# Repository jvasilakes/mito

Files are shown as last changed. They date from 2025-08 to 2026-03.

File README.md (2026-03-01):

# Mito

A tiny, cheap, hackable, completely open-source force gauge for isometric finger strength training.

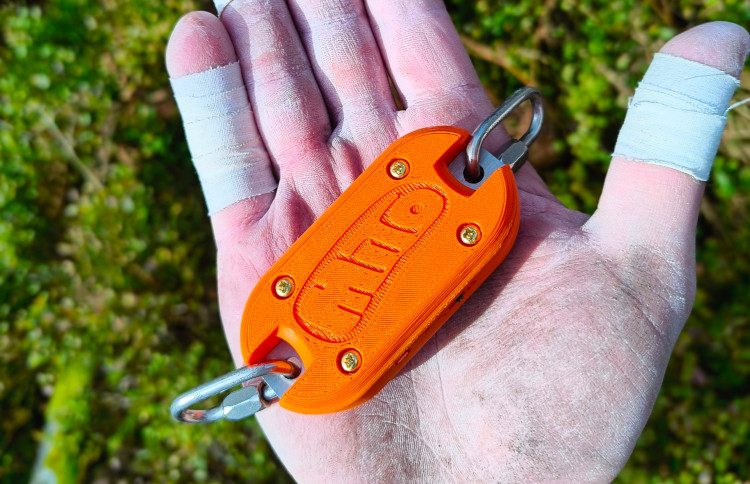
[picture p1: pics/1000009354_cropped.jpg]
Mito


## Hardware information

The Mito is based on the Seeed XIAO NRF52840 microcontroller, an HX711 ADC, and a custom load cell. It runs at approximately 80 samples per second on the hardware side, and sends approximately 60 samples per second over bluetooth. Initial tests show a standard error of about 100g. The load cell and two Peguet 3.5mm stainless steel maillon rapides provide a working load limit of 220kg and a breaking load of 1100kg. 

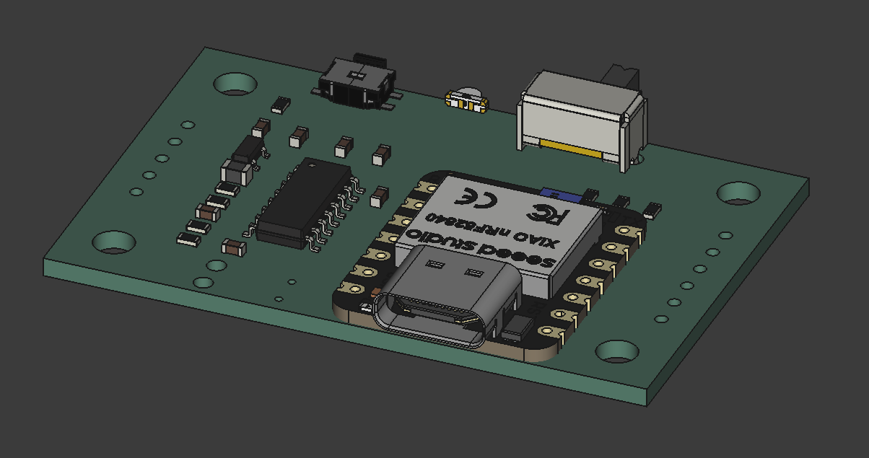
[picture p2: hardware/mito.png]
Mito PCB


## User Guide

On one side of your device you'll see

 1. A hardware on/off switch
 2. An LED indicator
 3. A tare button

On the other there is a USB-C port that is used for battery charging and firmware updates.

Assuming you've obtained a prebuilt device, it should be ready to go out of the box. Flip the switch to turn it on, and you'll see a green light for 1 second before it changes to yellow. Download the Frez app on your phone, register/sign in to your account, then press the "connect" button on the main page. If the Mito is powered on, a scan of available devices should reveal a device called "Progressor". Connect to it, register it as "Mito" or whatever name you like, and start training!

### Automatic sleep mode

After 1 minute of inactivity (i.e., no weight changes) the Mito will enter sleep mode to save battery. This is indicated by a periodic flashing LED. To wake your Mito up, simply press the tare button and continue your training. After 10 minutes in light sleep, the Mito will enter deep sleep from which it can only be woken up by turning it off and on again.

### Charging the battery

The Mito should need charging very infrequently. The current estimate is at least a few weeks of regular usage before the battery will run low. To charge, plug the Mito into a power source using a USB-C cable and turn it on with the hardware switch. The Mito will enter sleep mode after 1 minute of inactivity and continue to charge, indicated by a longer blinking LED.

### Firmware updates

Firmware updates will be provided here on the Releases page, so keep an eye out. To update your device's firmware with a new version, follow these steps:

 1. Download the new firmware UF2 file onto your computer (e.g., `mito_v0.0.1.uf2`).
 2. Plug your Mito into your computer using the USB-C port while holding down the tare button. Release the button once you see the red light. You've now entered maintenance mode selection.
 3. Use single presses of the tare button to cycle through the maintenance modes until you see a blue light, which indicates firmware update mode. Double click the tare button to select it.
 4. The Mito should turn off and after a few moments a USB device called XIAO-SENSE should pop up on your computer. Simply drag and drop the new UF2 file onto the root folder of this device. Once the copy is complete, the Mito should reset.
 5. Unplug the USB cable and start training!

### Changing the default device mode

The Mito is compatible with the Frez app for visualizing and tracking your training sessions. By default the Mito is in Tindeq mode (yellow light), meaning that it pretends to be a Tindeq device. This mode currently provides the most stable and fastest bluetooth connection to the Frez app. The Tindeq app is currently not supported, and your experience may vary.

If for whatever reason you want your Mito to pretend to be a WH-06 (the original device around which Frez was built), follow these steps:

 1. Turn your Mito on with the hardware switch.
 2. While the initial green light is showing, press the tare button to enter device selection mode. The light should turn blue.
 3. A single press of the tare button will cycle through the available device modes. Blue indicates the WH-06 while yellow indicates the Tindeq.
 4. Press the tare button twice quickly to change the default device to the current selection. The Mito will start up and from now on will be in your chosen device mode every time you turn it on.

If you want to abort this and stay with your current default device, simply turn the Mito off and back on again.

## Known Issues

### Frez Connectivity

It can happen that if you connect your Mito to Frez or another app (e.g., Tindeq), close the app, and the try to reconnect, the initialization will hang and you'll get a device disconnected error. This can be fixed by simply turning the Mito off and on again, and restarting the app.

### Battery Level Indicator

Frez shows battery level next to the connected device icon in the lower right corner. Unfortunately, the battery level sampling on the XIAO microcontroller isn't the most accurate, so you may see inconsistnet values. Overall, however, a low battery indication here is a good sign its time to charge.

## Advanced Usage

### Calibration

All pre-built Mito's are already calibrated. If you need to redo it however, follow these steps:

 1. Download [Serial Bluetooth Terminal](https://play.google.com/store/apps/details?id=de.kai_morich.serial_bluetooth_terminal&pcampaignid=web_share) app on your phone. 
 2. Turn on the Mito while holding down the tare button to enter maintenance mode.
 3. Use single presses of the tare button to cycle through modes until you see a white light. Press the tare button twice quickly to select this, which will enter calibration mode.
 4. Open the Serial Bluetooth Terminal app, scan for devices, and select the Mito.
 5. A terminal window should open. Hang the Mito on something solid, but keep the other anchor free. Once you see `Connecting to Mito... Connected` in the terminal window, send an empty command to start the calibration process. 
 6. After you see `Tared. Enter weight. grams: ` in the terminal, hang a known weight on the free anchor of the Mito. Make sure the weight is stationary and not swinging, twirling, etc.
 7. Enter the weight in grams (e.g., for a 20kg plate you would enter `20000`) and hit send.
 8. The calibration will now run for a few iterations. At the end it will print `Estimated parameter:  Saving...`. 
 9. Power cycle the Mito, connect to the Frez app, and validate that the reading is correct for the weight you used to calibrate. 

### Configuration

You can manually set the following variables in `prototype/src/lib/config.h`. For the changes to take effect, you will need to recompile and upload the firmware to your Mito (see below).

 * `LIGHT_SLEEP_SECONDS`: The number of seconds with no weight changes until the Mito enters light sleep. Default 60.
 * `DEEP_SLEEP_SECONDS`: The number of seconds in light sleep until the Mito enters deep sleep. Default 600.
 * `SCALE_FACTOR`: The calibration scale factor. Default set during calibration (see above). This can be used to fine-tune your precise calibration factor.

### Building the firmware

First, clone this repository or download the code for your chosen release. Then,

```
cd dev
arduino-cli compile --export-binaries --fqbn Seeeduino:nrf52:xiaonRF52840Sense prototype
python ../utils/uf2conv.py prototype/build/Seeeduino.nrf52.xiaonRF52840Sense/prototype.ino.hex --family 0xADA52840 --convert --output prototype/releases/mito_vX.X.X.uf2 
```

Change the `X.X.X` to your desired version. If you've made changes to an official release, I recommend adding a suffix to indicate it (e.g., `mito_v0.0.4_dev.uf2`).

### Debug Mode

If you're doing development and want to access information over serial, plug your Mito into your computer while holding down the tare button. Use single presses of the tare button until you see a red light. Double click the tare button to enter debug mode. In this mode, the Mito will not start its initialization routine until you've connected to it with a serial monitor. 

Once the Mito has begun measuring, it will print data in the following format for each measurement taken from the ADC:

`adc_reading,smoothed_adc_reading,scale_offset,scale_calibration_factor,weight_grams,device_sample_rate_hz,ble_notify_rate_hz,battery_is_charging,battery_voltage,battery_percentage`

It will also print out any commands it receives from the central, and when the device is charging in sleep mode it will print out the current battery percentage.

### Entering firmware update mode with the hardware reset button

It might happen that a failed firmware update means that you can't enter firmware update mode using the method described above. If this happens you'll have to use the hardware reset button on the microcontroller. You can do this in two ways:

 1. Insert a small thin object into the hole below the 'S' on the CRUX TOOLS side of the Mito. a bobby pin works great for this. You'll have to fish around a bit, but the XIAO's reset button should be directly below this. Do your best to double click it. If you're successful, the Mito will turn off and you'll see the XIAO-SENSE USB device pop up on your computer. 
 2. If the above is simply too annoying, you can also open the case using a standard Philip's head screwdriver. If you do this, there is a chance you will have to re-calibrate after putting it together again, since the load cell can get shifted slightly.

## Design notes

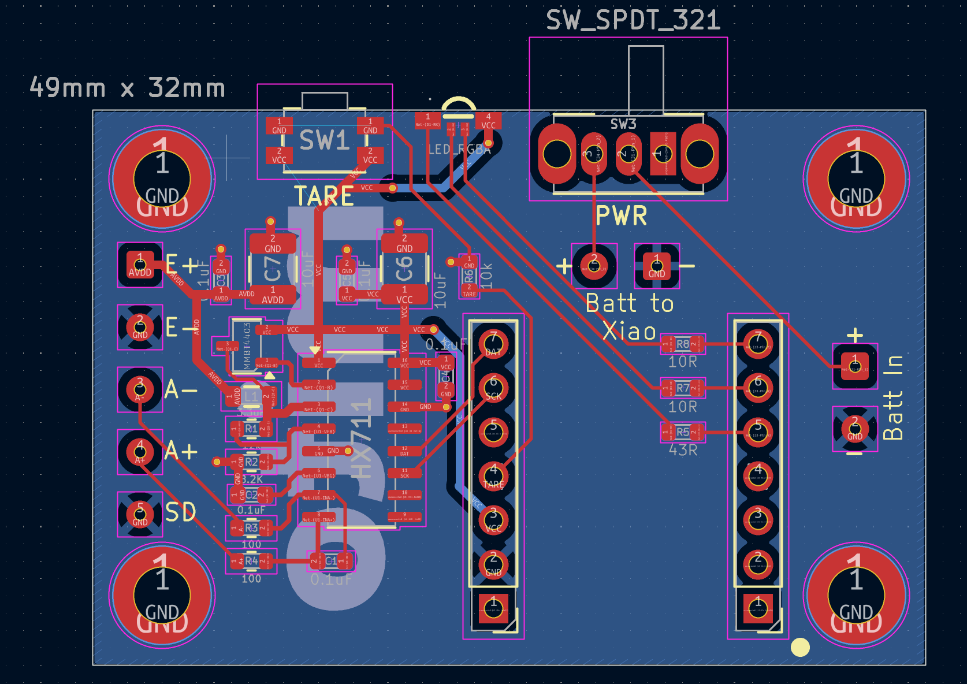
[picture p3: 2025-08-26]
hardware/img/pcb.png

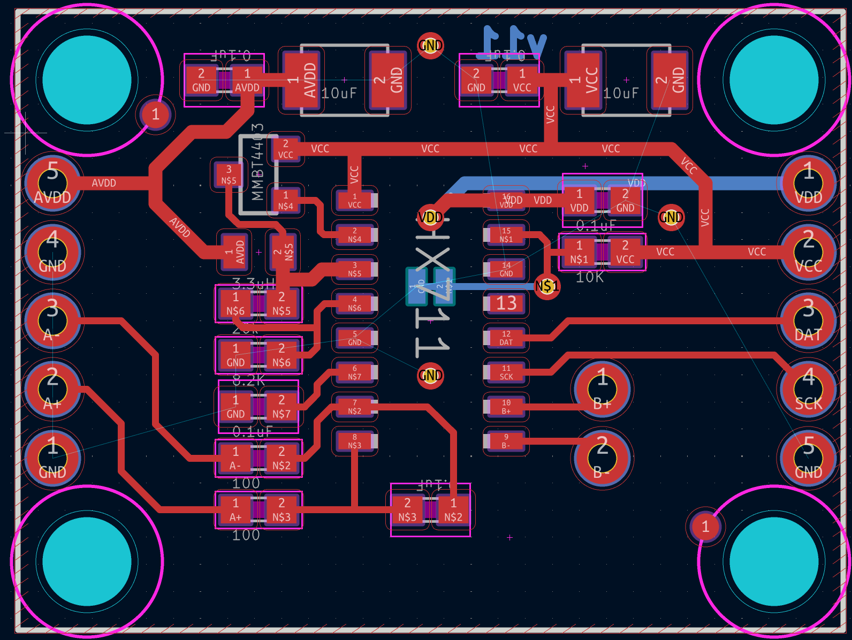
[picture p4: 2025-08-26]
hardware/sparkfun_layout.png

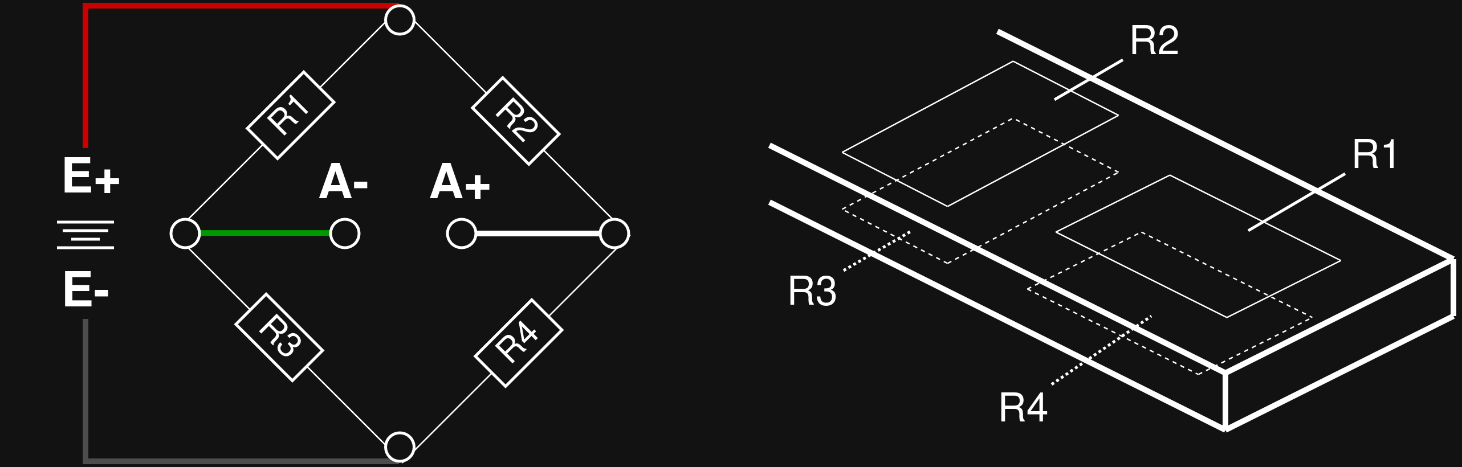
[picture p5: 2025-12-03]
pics/load_cell_diagram.png

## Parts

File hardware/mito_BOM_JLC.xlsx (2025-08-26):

reference | quantity | value | footprint | part_number
R1 | 1 | 12k | R_0603 | C22790
R2 | 1 | 8.2K | R_0603 | C309082
R3,R4,R8,R7 | 4 | 100R | R_0603 | C25201
R5 | 1 | 180R | R_0603 | C25210
R6 | 1 | 10k | R_0603 | C95204
C1,C2,C3,C4,C5 | 5 | 0.1uF | C_0603 | C24452
C6,C7 | 2 | 10uF | C_1210 | C39232
L1 | 1 | 3.3uH | L_0805 | C51725
Q1 | 1 | MMBT4403 | SOT-23-3 | C8513
U1 | 1 | HX711 | SOIC-16_3.9x9.9mm_P1.27mm | C6705483
D1 | 1 | LED_RGBA | LED-SMD_LTST-S310F3WT | C284951
SW1 | 1 | SW_Push | Panasonic_EVQPUJ_EVQPUA | C128539
PWR | 1 | SW_SPDT_321 | SW_Slide_SPDT_Angled_CK_OS102011MA1Q | C226259

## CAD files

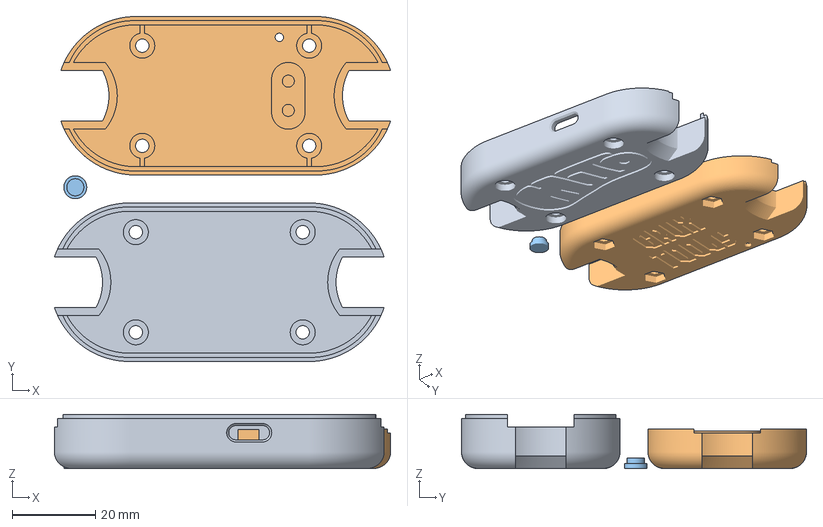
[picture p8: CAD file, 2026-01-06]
hardware/enclosure/enclosure_v3.3mf
80.6 x 82.7 x 13.0 mm
enclosure3-Bottom
enclosure3-Top
button3

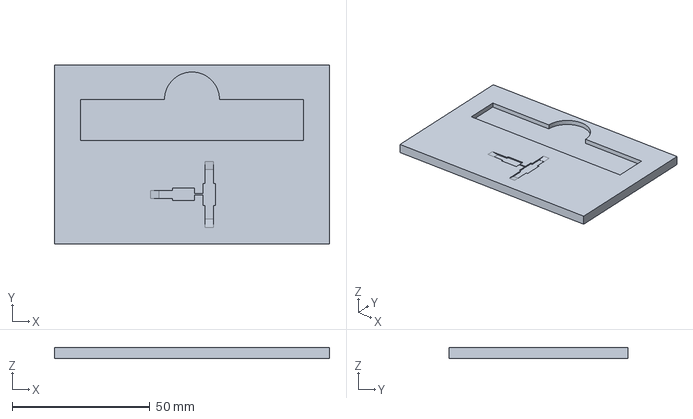
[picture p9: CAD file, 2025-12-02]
hardware/load_cell/build_plate.FCStd
100.0 x 65.0 x 4.00 mm

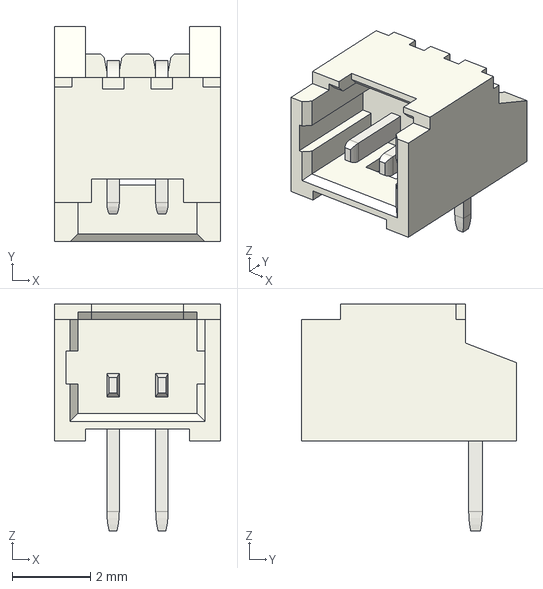
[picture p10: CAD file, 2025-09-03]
hardware/Molex_PicoBlade_53048-0210.stp
4.25 x 5.50 x 5.80 mm

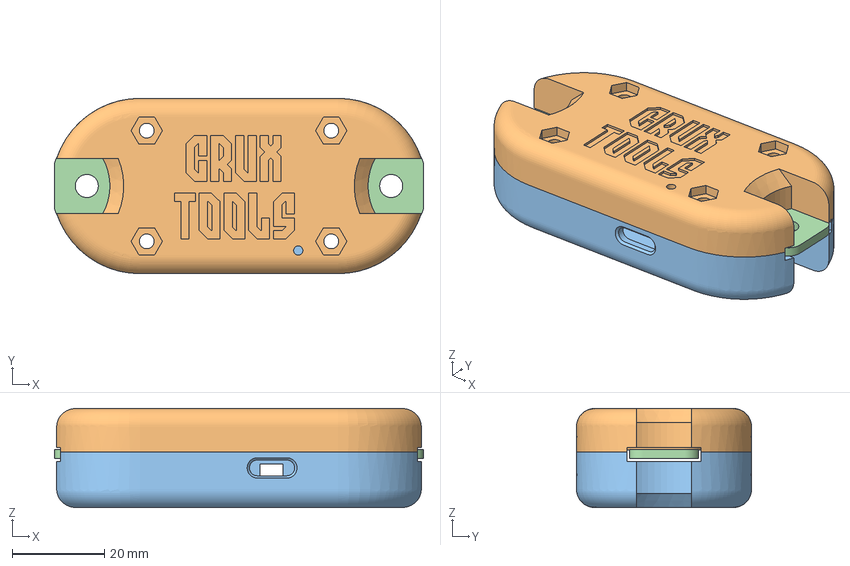
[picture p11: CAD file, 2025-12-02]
hardware/enclosure/enclosure2.FCStd
80.0 x 38.0 x 21.5 mm
button_cutout003
top
bottom
load_cell

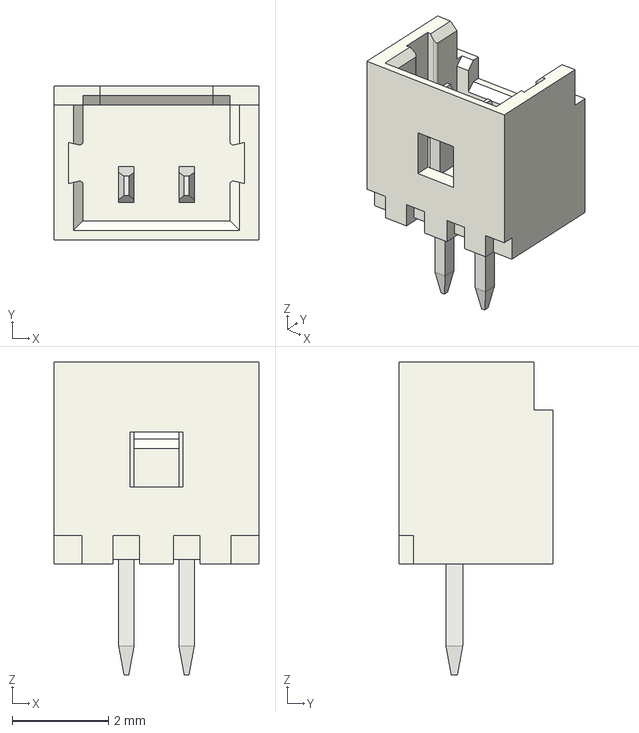
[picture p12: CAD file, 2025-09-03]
hardware/Molex_PicoBlade_53047-0210.stp
4.25 x 3.20 x 6.50 mm

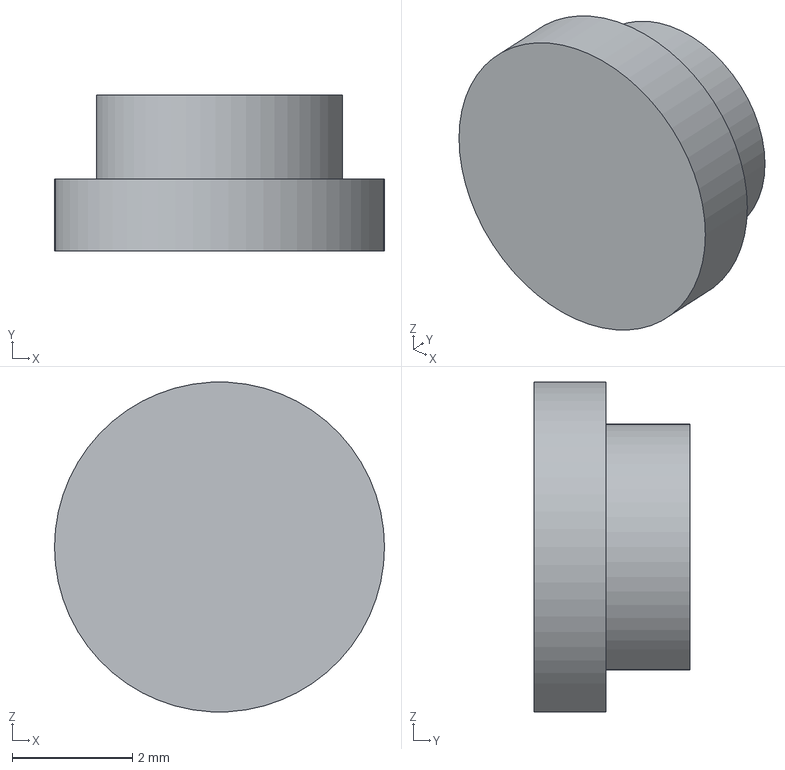
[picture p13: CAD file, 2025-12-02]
hardware/enclosure/button3.step
5.50 x 2.60 x 5.49 mm

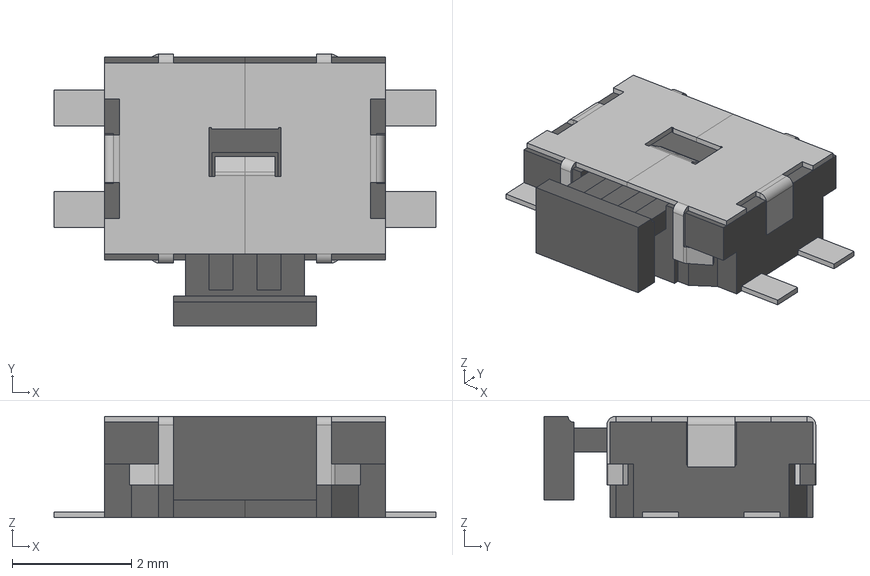
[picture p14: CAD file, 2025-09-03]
hardware/Panasonic_EVQPUJ_EVQPUA.step
6.40 x 4.55 x 1.70 mm

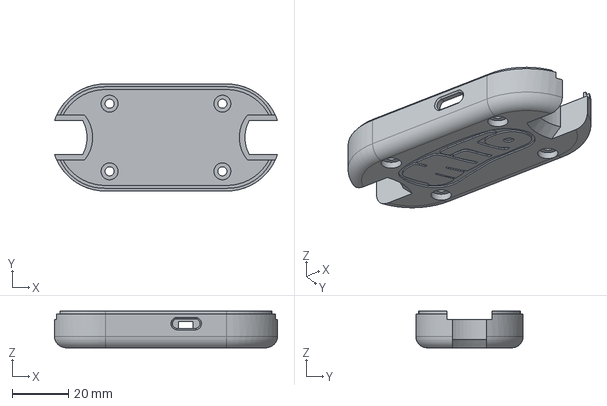
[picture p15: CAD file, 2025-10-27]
hardware/enclosure/enclosure3-Bottom.step
79.1 x 38.0 x 13.0 mm

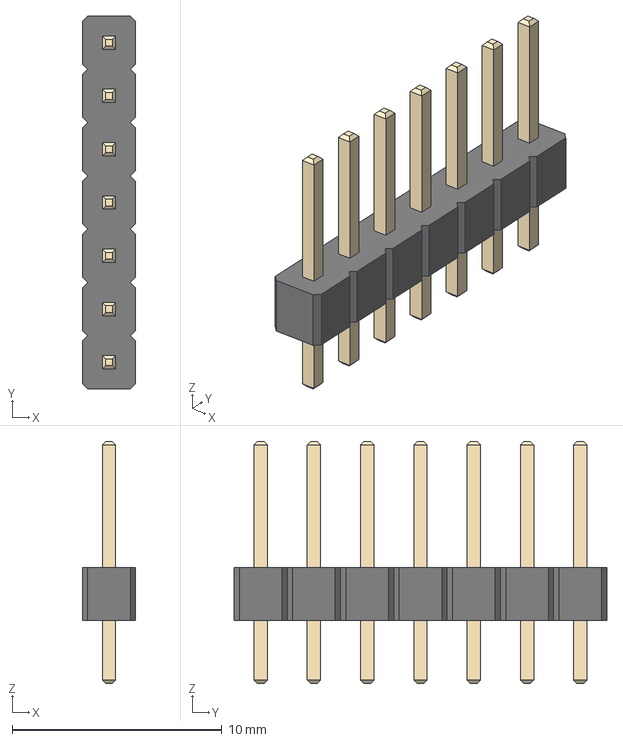
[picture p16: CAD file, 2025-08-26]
hardware/PinHeader_1x07_P2.54mm_Vertical.step
2.54 x 17.8 x 11.5 mm

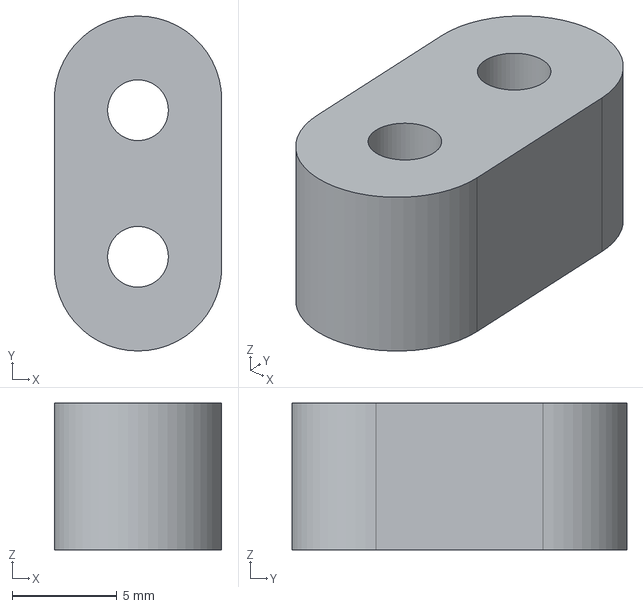
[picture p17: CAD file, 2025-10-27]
hardware/enclosure/load_cell_standoff.step
8.00 x 16.0 x 7.00 mm

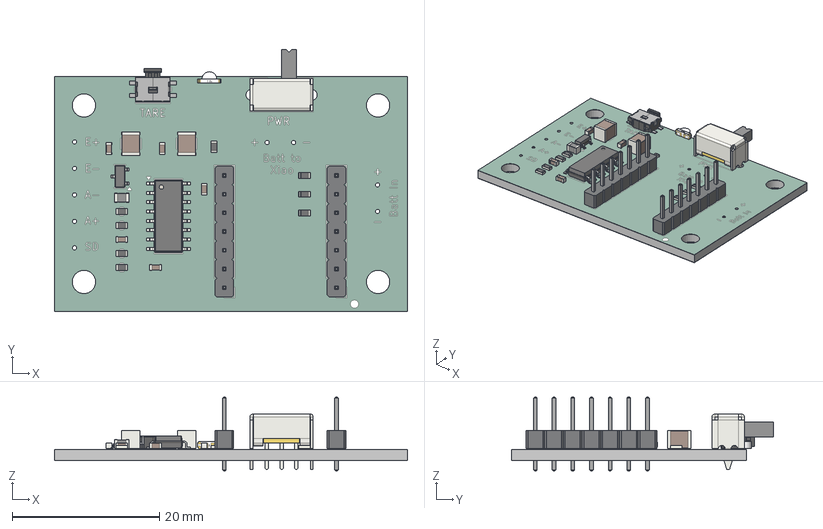
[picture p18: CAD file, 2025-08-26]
hardware/mito.step
48.0 x 35.7 x 10.0 mm
R_0603 x 4
R_0603_1608Metric x 4
SW_Slide_SPDT_Angled_CK_OS102011MA1Q
pinheader_short-pinheader x 2
C_0603 x 5
LED-ARRAY-SMD_4P-L3.2-W1.5-H1.0
C_1210_3225Metric x 2
SOIC-16_3.9x9.9mm_P1.27mm
L_0805
Pocket008_(Mirror_#2)
Pad007_(Mirror_#3)
Pad007_(Mirror_#5)
Pad007_(Mirror_#4)
SOT-23-3
mito_silkscreen
mito_soldermask
mito_PCB

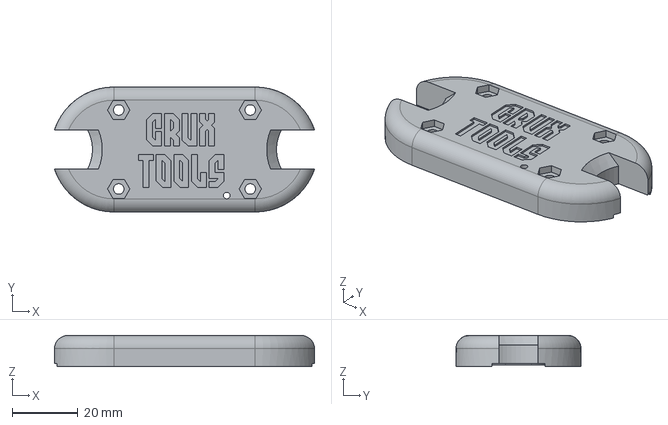
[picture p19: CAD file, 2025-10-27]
hardware/enclosure/enclosure3-Top.step
79.1 x 38.0 x 9.50 mm

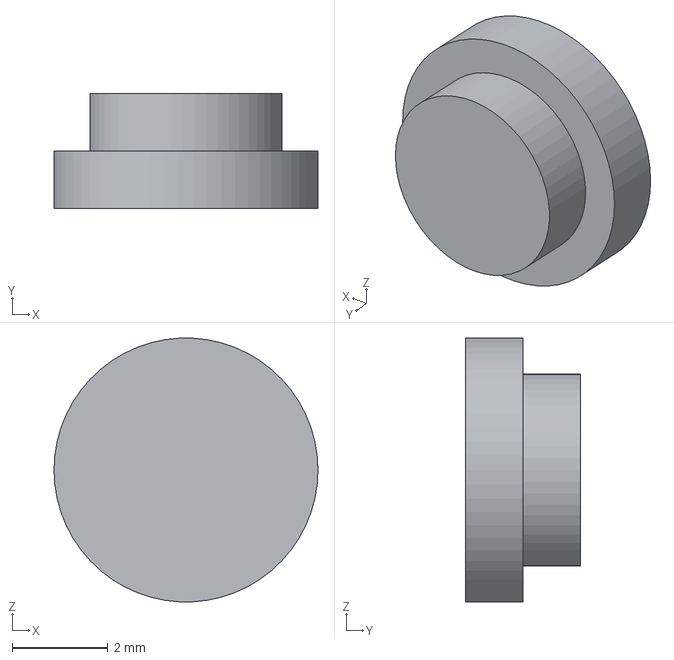
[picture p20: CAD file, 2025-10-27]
hardware/enclosure/button2.step
5.50 x 2.40 x 5.49 mm

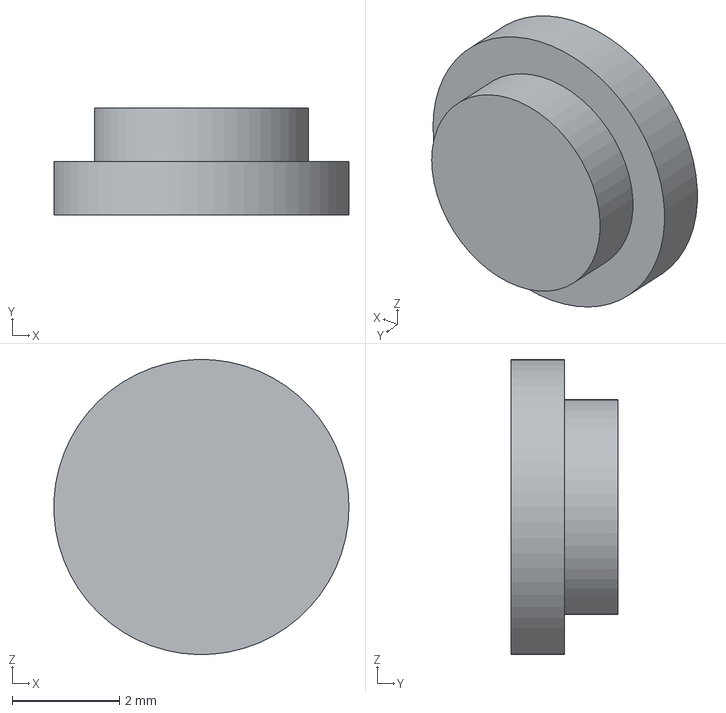
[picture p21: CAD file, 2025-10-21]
hardware/enclosure/button.step
5.50 x 2.00 x 5.50 mm

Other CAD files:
hardware/enclosure/enclosure2-Bottom.step
hardware/enclosure/enclosure2-Top.step
hardware/enclosure/enclosure_bottom_with_window.3mf
hardware/enclosure/enclosure_bottom.3mf
hardware/enclosure/enclosure.FCStd
hardware/enclosure/enclosure2-Bottom_window.step
hardware/enclosure/enclosure2-Bottom_with_window.step
hardware/enclosure/load_cell.stl
hardware/enclosure/transparent_test.3mf
hardware/load_cell/build_plate.3mf
hardware/load_cell/build_plate.stl

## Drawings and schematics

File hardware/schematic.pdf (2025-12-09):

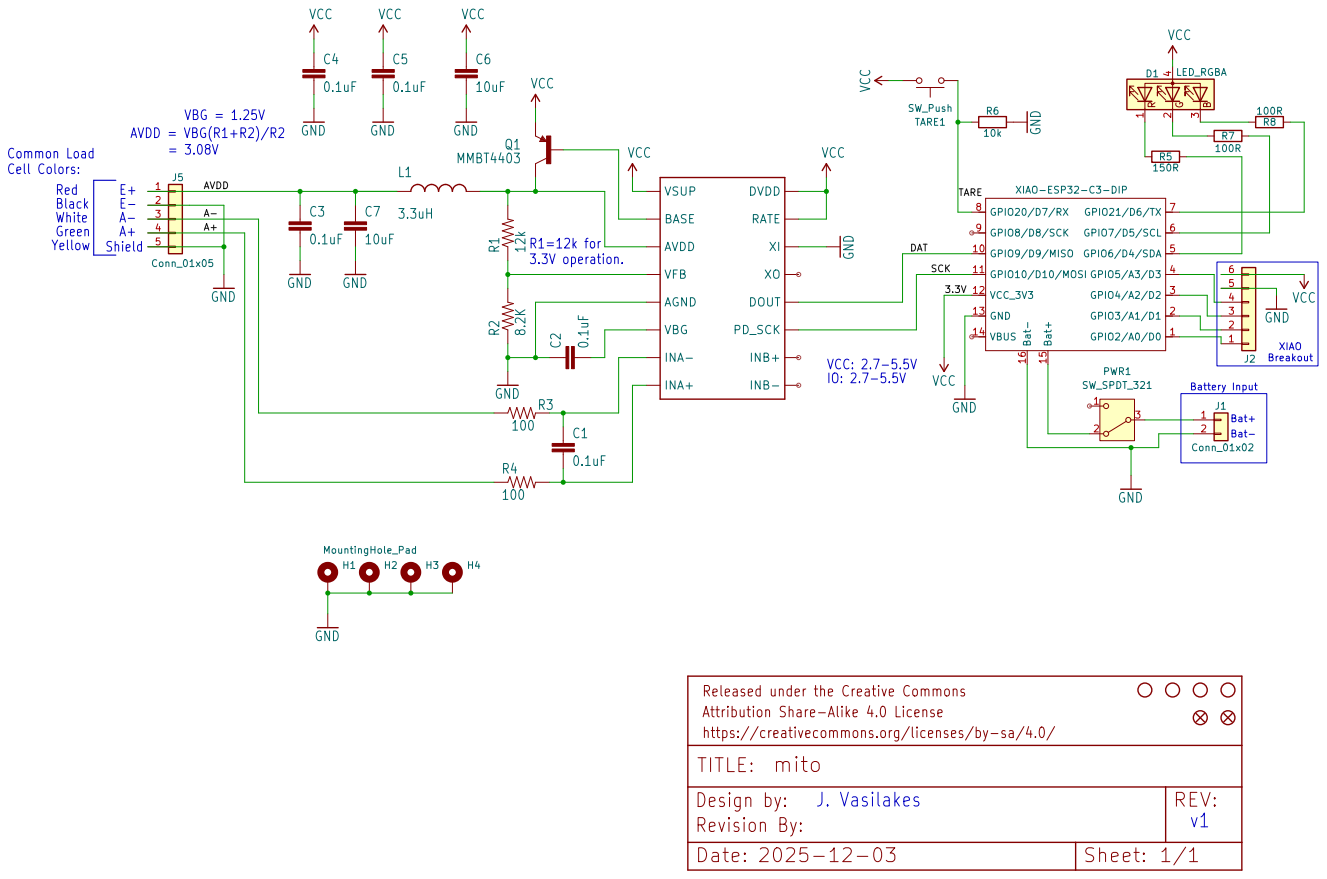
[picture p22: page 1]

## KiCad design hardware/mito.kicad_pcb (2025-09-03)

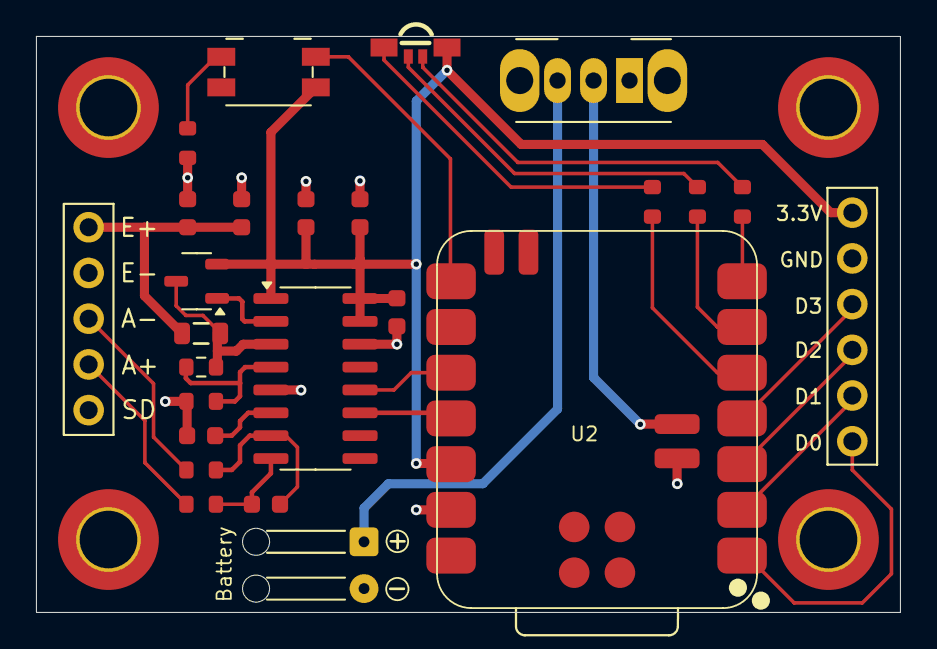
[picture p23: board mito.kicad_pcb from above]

Board: 2 copper layers, 48.0 x 32.0 mm, 30 parts (0 on the bottom side), 26 nets.

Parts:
C1, C2, C3, C4, C5: 0.1uF; C_0603
C6, C7: 10uF; C_0603
D1: LED_RGBA; LED-SMD_LTST-S310F3WT
FRAME1: FRAME-LETTER; CREATIVE_COMMONS
H1, H2, H3, H4: MountingHole_Pad; MountingHole_3.2mm_M3_DIN965_Pad_TopOnly
J1: Conn_01x02; SolderWire-0.1sqmm_1x02_P3.6mm_D0.4mm_OD1mm_Relief
J2: Conn_01x06; PinHeader_1x06_P2.54mm_Vertical
J5: Conn_01x05; PinHeader_1x05_P2.54mm_Vertical
L1: 3.3uH; L_0805
PWR1: SW_SPDT_321; SW_Slide_SPDT_Angled_CK_OS102011MA1Q
Q1: MMBT4403; SOT-23-3
R1: 12k; R_0603_1608Metric
R2: 8.2K; R_0603
R3, R4: 100; R_0603
R5: 150R; R_0603
R6: 10k; R_0603
R7, R8: 100R; R_0603
TARE1: SW_Push; Panasonic_EVQPUJ_EVQPUA
U1: HX711; SOIC-16_3.9x9.9mm_P1.27mm
U2: XIAO-ESP32-C3-DIP; XIAO-nRF52840-SMD

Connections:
/A+: J5.4, R4.1
/A-: J5.3, R3.1
/AVDD: C3.1, C7.1, J5.1, L1.1
/DAT: U1.12 (DOUT), U2.10 (GPIO9/D9/MISO)
/SCK: U1.11 (PD_SCK), U2.11 (GPIO10/D10/MOSI)
/TARE: R6.1, TARE1.1, U2.8 (GPIO20/D7/RX)
GND: C2.1, C3.2, C4.2, C5.2, C6.2, C7.2, H1.1, H2.1, H3.1, H4.1, J1.2, J2.5, J5.2, J5.5, R2.1, R6.2, U1.5 (AGND), U1.14 (XI), U2.13 (GND), U2.16 (Bat-)
unnamed: D1.3 (BK), R8.1
unnamed: D1.2 (GK), R7.1
unnamed: D1.1 (RK), R5.1
unnamed: J1.1, PWR1.3 (B)
unnamed: J2.1, U2.1 (GPIO2/A0/D0)
unnamed: J2.2, U2.2 (GPIO3/A1/D1)
unnamed: J2.3, U2.3 (GPIO4/A2/D2)
unnamed: J2.4, U2.4 (GPIO5/A3/D3)
unnamed: PWR1.2 (A), U2.15 (Bat+)
unnamed: Q1.1 (B), U1.2 (BASE)
unnamed: L1.2, Q1.3 (C), R1.2, U1.3 (AVDD)
unnamed: C1.2, R4.2, U1.8 (INA+)
unnamed: C1.1, R3.2, U1.7 (INA-)
unnamed: C2.2, U1.6 (VBG)
unnamed: R1.1, R2.2, U1.4 (VFB)
unnamed: R5.2, U2.5 (GPIO6/D4/SDA)
unnamed: R7.2, U2.6 (GPIO7/D5/SCL)
unnamed: R8.2, U2.7 (GPIO21/D6/TX)
VCC: C4.1, C5.1, C6.1, D1.4 (A), J2.6, Q1.2 (E), TARE1.2, U1.1 (VSUP), U1.15 (RATE), U1.16 (DVDD), U2.12 (VCC_3V3)

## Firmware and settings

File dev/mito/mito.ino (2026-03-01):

#include <iostream>
#include <memory>
#include <string.h>
#include <Adafruit_TinyUSB.h>
#include "lib/config.h"
#include "lib/battery.h"
#include "lib/HX711.h"
#include "lib/flash.h"
#include "lib/scales.h"


/* Set in setup() */
uint8_t DEVICE_CODE;  // 0: WH06  1: Tindeq
int NUM_DEVICES = 2;

// Tare button
const uint8_t tarePin = 7;  // the tare button
bool tareState = 0;  // tare button push state.

bool debug = 0;  // Enter debug mode, which opens serial over usb.
bool doCalibrate = 0;  // Enter calibration mode.
bool enter_dfu = 0;  // Enter DFU mode and reset.

// RGB LED pins
const uint8_t redPin = 4;    // the number of the LED pin
const uint8_t greenPin = 5;    // the number of the LED pin
const uint8_t bluePin = 6;    // the number of the LED pin
// Current LED color
uint8_t color[3] = { 0, 0, 0 };

// Load Cell parameters
const uint8_t LOADCELL_DOUT_PIN = 9;
const uint8_t LOADCELL_SCK_PIN = 10;
const uint8_t LOADCELL_GAIN = 128;

// Parameter for Exponential Moving Average
int WEIGHT_EMA_ALPHA = 75;
int BATT_EMA_ALPHA = 10;

/* ========== Global Variables ========== */
bool first_loop = 1;
long reading = 0;  // Raw ADC reading.
long smoothed_reading = 0;  // For computing exponential moving average.
uint32_t weight = 0;  // Current weight reading in grams.
uint32_t prev_weight = 0;  // Previous weight reading in grams.

uint32_t curr_time = 0;  // Current time stamp
uint32_t prev_time = 0;  // To measure increments without delay() 

uint32_t measure_time = 0;  // Microseconds since measurement started
uint32_t start_measure_time = 0;  // Microseconds since measurement started
uint32_t hz_time = 0;    // For measuring device and BLE Hz
bool currently_measuring = 0;

// Convert to milliseconds
uint32_t light_sleep_timeout = LIGHT_SLEEP_SECONDS * 1000;
uint32_t deep_sleep_timeout = DEEP_SLEEP_SECONDS * 1000;
uint32_t sleepTimeoutStart = 0;

uint16_t num_samples = 0;  // Number of samples obtained from the ADC
uint16_t num_packets = 0;  // Number of samples obtained from the ADC
uint16_t device_hz = 0;    // For measuring HX711 speed
uint16_t ble_hz = 0;       // For measuring BLE speed

float avg_battery_voltage = 0.0;
float prev_vbat = -1.0;

/* ========= The device =========== */
HX711 scale;  // The HX711 ADC
Device* device = nullptr;  // The overall device: WH06, Tindeq
XiaoBattery battery;  // The battery ADC

void setLEDColor(uint8_t red, uint8_t green, uint8_t blue)
{
  // Set the LED color based on RGB values.
  // Assumes common anode RGB LED
  digitalWrite(redPin, 255 - red);
  digitalWrite(greenPin, 255 - green);
  digitalWrite(bluePin, 255 - blue);
}

uint8_t* getLEDColor(void)
{
  uint8_t* rgb = new uint8_t[3];
  rgb[0] = 255 - digitalRead(redPin); 
  rgb[1] = 255 - digitalRead(greenPin); 
  rgb[2] = 255 - digitalRead(bluePin); 
  return rgb;
}

void turnOffLED(void)
{
  // Turn off the LED.
  digitalWrite(redPin, HIGH);
  digitalWrite(greenPin, HIGH);
  digitalWrite(bluePin, HIGH);
}

void flashLED(void)
{
  // Flash the LED on and off with the current color.
  // Used to indicate tare.
  uint8_t* rgb = getLEDColor();
  for (int i=0; i<3; i++) {
    turnOffLED();
    delay(100);
    setLEDColor(rgb[0], rgb[1], rgb[2]);
    delay(100);
  }
  delete[] rgb;
}

template <typename T>
void debugPrint(T msg)
{
  if (debug == 1) {
    Serial.print(msg);
  }
}

template <typename T>
void debugPrintln(T msg)
{
  if (debug == 1) {
    Serial.println(msg);
  }
}

void tare(void)
{
  debugPrintln("Taring...");
  scale.tare();
  flashLED();
}

void quickTare(void)
{
  // Same as tare but don't flash the LED.
  debugPrintln("Quick Tare...");
  scale.tare(1);
}

int getWeight(void)
{
  int maxr;
  int minr;
  int midr;
  int rval = 0;
  // Take a reading from the HX711.
  // Remove the upper and lower outlier
  for (int i=0; i<3; i++) {
    if (scale.is_ready()) {
      reading = scale.read_average(1);
      rval = 1;
    }
    if (i == 0) {
      maxr = reading;
      minr = reading;
      midr = reading;
    } else {
      if (reading > maxr) {
        maxr = reading;
      } else if (reading < minr) {
        minr = reading;
      } else {
        midr = reading;
      }
    }
  }
  if (smoothed_reading == 0) {
    smoothed_reading = midr;
  }
  // Exponential moving average filter.
  smoothed_reading = ((WEIGHT_EMA_ALPHA * midr) + ((100 - WEIGHT_EMA_ALPHA) * smoothed_reading))/100;
  int numerator; 
  if (smoothed_reading < scale.OFFSET) {
    numerator = 0;
  } else {
    numerator = smoothed_reading - scale.OFFSET;
  }
  weight = numerator / scale.SCALE;
  // Don't register anything under 100 grams.
  // This is a bit of a hack to get around possible
  // load cell sensitivity issues.
  if (weight < 100) {
    weight = 0;
  } else {
    // Round weight to nearest 50 grams
    weight = weight - (weight % 50);
  }

  debugPrint(reading);
  debugPrint(",");
  debugPrint(smoothed_reading);
  debugPrint(",");
  debugPrint(scale.OFFSET);
  debugPrint(",");
  debugPrint(scale.SCALE);
  debugPrint(",");
  debugPrint(weight);
  debugPrint(",");
  debugPrint(device_hz);
  debugPrint(",");
  debugPrint(ble_hz);
  debugPrint(",");
  debugPrint(battery.IsChargingBattery());
  debugPrint(",");
  debugPrint(avg_battery_voltage);
  debugPrint(",");
  debugPrintln(getBatteryPercentage());
  return rval;
}

float getBatteryPercentage() {
  float vbat = battery.GetBatteryVoltage();
  // There is some noise in the battery charging ADC
  // If vbat is much greater than the previous reading
  // Just keep the lower reading.
  if (prev_vbat == -1.0) { prev_vbat = vbat; }
  if (vbat - prev_vbat > 0.1) {
    vbat = prev_vbat;
  } else {
    prev_vbat = vbat;
  }
  avg_battery_voltage = ((BATT_EMA_ALPHA * vbat) + ((100 - BATT_EMA_ALPHA) * avg_battery_voltage))/100;
  if (avg_battery_voltage <= 3.3) {
    return 0.0;
  } else if (avg_battery_voltage >= 4.2) {
    return 1.0;
  } else {
    return (avg_battery_voltage - 3.3) / (4.2 - 3.3);
  }
}

/* Count the number of times the tare button
   is pressed within a millisecond window */
int countTarePresses(int window)
{
  window *= 1000;  // since curr/prev_time are microseconds.
  curr_time = micros();
  prev_time = micros();
  int count = 0;
  int newState = LOW;
  int oldState = LOW;
  while (curr_time - prev_time < window) {
    newState = digitalRead(tarePin);
    if (newState != oldState) {
      if (newState == LOW) {
        // oldState is HIGH, so the button was pressed then released.
        count += 1;
      }
      oldState = newState;
    }
    curr_time = micros();
    delay(50);  // Debounce the button.
  }
  curr_time = micros();
  prev_time = micros();

  return count;
}

void enterDeepSleep() {
  flashLED();
  if (battery.IsChargingBattery()) {
    // set LED to a color indicating charging
  } else {
    turnOffLED();
  }
  uint8_t wakePin = g_ADigitalPinMap[tarePin];  // Map Arduino pin to nRF pin
  nrf_gpio_cfg_sense_input(wakePin, NRF_GPIO_PIN_PULLDOWN, NRF_GPIO_PIN_SENSE_HIGH);
  NRF_POWER->SYSTEMOFF = 1;
}

void lightSleep() {
  uint8_t* rgb = getLEDColor();
  flashLED();
  scale.power_down();
  turnOffLED();
  int sleep_start_time = millis();
  while (1) {
    tareState = digitalRead(tarePin);
    if (tareState == HIGH) {
      break;
    }
    if (sleepTimeoutStart > 0 && ((millis() - sleepTimeoutStart) > deep_sleep_timeout)) {
      if (DEVICE_CODE != 1) {
        // Don't enter deep sleep when Tindeq, as this will end the training
        //   session in the app without saving progress. Annoying if you've programmed
        //   in rests longer than 3 minutes.
        // If we enter deep sleep, a full system reset will occur on exit.
        enterDeepSleep();
      }
    }
    int blink_time = 100;
    uint8_t blink_rgb[3] = { 0 };
    if (battery.IsChargingBattery()) {
      float batt_level = getBatteryPercentage();
      debugPrintln(batt_level);
      blink_time = 1500;
      // Pulse LED with charge status color
      // Green, yellow, red.
      if (batt_level >= 0.75) {
        blink_rgb[0] = 0;
        blink_rgb[1] = 255;  // Green
        blink_rgb[2] = 0;
      } else if (batt_level >= 0.25) {
        blink_rgb[0] = 255;
        blink_rgb[1] = 255;  // Yellow
        blink_rgb[2] = 0;
      } else {
        blink_rgb[0] = 255;  // Red
        blink_rgb[1] = 0;
        blink_rgb[2] = 0;
      }
    } else {
      blink_rgb[0] = rgb[0];
      blink_rgb[1] = rgb[1];
      blink_rgb[2] = rgb[2];
    }
    if (millis() - sleep_start_time >= 2000) {
      setLEDColor(blink_rgb[0], blink_rgb[1], blink_rgb[2]);
      delay(blink_time);
      turnOffLED();
      sleep_start_time = millis();
    }
  }
  scale.power_up();
  setLEDColor(rgb[0], rgb[1], rgb[2]);
  flashLED();
}

void setup()
{
  // initialize the tare button.
  pinMode(tarePin, INPUT);
  // initialize the LED.
  pinMode(redPin, OUTPUT);
  pinMode(greenPin, OUTPUT);
  pinMode(bluePin, OUTPUT);

  // Initialize with the current battery voltage.
  avg_battery_voltage = battery.GetBatteryVoltage();

  initFlash();
  DEVICE_CODE = readDefaultDevice();

  // Initialize the scale
  scale.begin(LOADCELL_DOUT_PIN, LOADCELL_SCK_PIN, LOADCELL_GAIN);
  delay(250);
  scale.power_up();

  // If tare held at startup, enter debug or calibrate mode
  tareState = digitalRead(tarePin);
  if (tareState == HIGH) {
    int num_presses;
    int interrupt_mode = 0;
    while (1) {

      switch (interrupt_mode) {
        case 0:  // debug mode
          setLEDColor(255, 180, 0);  // orange
          debug = 1;
          doCalibrate = 0;
          enter_dfu = 0;
          break;
        case 1:  // run calibrate
          setLEDColor(255, 255, 255);  // white
          debug = 0;
          doCalibrate = 1;
          enter_dfu = 0;
          break;
        case 2:  // DFU
          setLEDColor(225, 0, 255);  // purple
          debug = 0;
          doCalibrate = 0;
          enter_dfu = 1;
      } // end switch interrupt_mode

      num_presses = countTarePresses(1000);
      if (num_presses == 1) {
        // Cycle to the next option
        interrupt_mode = (interrupt_mode + 1) % 3;
      } else if (num_presses == 2) {
        // Select the current option
        flashLED();
        if (enter_dfu == 1) {
          // See https://forums.adafruit.com/viewtopic.php?t=218553
          NRF_POWER->GPREGRET = 0x57;  // DFU_MAGIC_UF2_RESET
          NVIC_SystemReset();
        } else if (doCalibrate == 1) {
          device = new Mito();
          // Downcast to Mito to access calibrate()
          if (Mito* mito = static_cast<Mito*>(device)) {
            mito->calibrate(scale);
            NVIC_SystemReset();
          } else {
            // Something went terribly wrong.
            setLEDColor(255, 0, 0);
            while (1) { flashLED(); }
          }  // end if downcast
        }  // end if doCalibrate 
        break;
      } else { continue; }
    }  // end while

  // If the button is not held, show green for 1s at startup
  // allowing user to press tare to enter different modes.
  } else {
    setLEDColor(0, 255, 0);  // green
    int num_presses = countTarePresses(1000);
    if (num_presses > 0) {
      /* If tare pressed, enter device selection */
      flashLED();
      uint8_t curr_device = 0;  // WH06
      while (1) {
        switch (curr_device) {
          case 0:  // WH06
            setLEDColor(0, 200, 255);  // light blue
            break;
          case 1:  // Tindeq
            setLEDColor(255, 255, 0);  // yellow
            break;
        }
        num_presses = countTarePresses(1000);
        if (num_presses == 1) {
          // Go to the next device.
          curr_device = (curr_device + 1) % NUM_DEVICES;
        } else if (num_presses == 2) {
          // Save the current device as default and exit the loop.
          DEVICE_CODE = curr_device;
          flashLED();
          saveDefaultDevice(DEVICE_CODE);
          break;
        }
      }
    }
  }

  if (debug == 1) {
    Serial.begin(115200);
    while ( !Serial ) delay(10);  // wait for serial connection
    Serial.println("Starting.");
  }

  if (scale.wait_ready_timeout(1000)) {
    debugPrintln("HX711 ready.");
  }

  // Initialize the device.
  switch (DEVICE_CODE) {
    case 0:
      setLEDColor(0, 200, 255);  // light blue
      device = new WH06();
      debugPrintln("Device: WH06");
      break;
    case 1:
      setLEDColor(255, 255, 0);  // yellow
      device = new Tindeq();
      debugPrintln("Device: Tindeq");
      break;
  }

  // Set the SCALE.
  float scale_param;
  #ifndef SCALE_FACTOR
    scale_param = readScaleParam();
  #else
    scale_param = SCALE_FACTOR;
  #endif
  debugPrint("Scale set to ");
  debugPrintln(scale_param);
  scale.set_scale(scale_param);
  tare();

  // Start BLE
  device->begin();
  debugPrintln("BLE Advertising");
}

void loop() {
  int weight_diff = prev_weight - weight;
  if (weight_diff < 0) {
    weight_diff *= -1;
  }
  // Detect differences of 100g or more only.
  if (sleepTimeoutStart == 0 || weight_diff >= 100) {
    sleepTimeoutStart = millis();
  }

  tareState = digitalRead(tarePin);
  // Tare when button pressed.
  if (tareState == HIGH) {
    tare();
  }

  // Get the command code from the central.
  char cmd = device->getCommand();
  switch (cmd) {
    case 0x64:  // Tare
      tare();
      break;
    case 0x65:  // Start measurement
      if (currently_measuring == 0) {
        quickTare();
        measure_time = start_measure_time = hz_time = micros();
      }
      currently_measuring = 1;
      break;
    case 0x66:  // Stop measurement
      currently_measuring = 0;
      break;
    case 0x6f:  // battery
      uint32_t mv = avg_battery_voltage * 1000.0;
      device->updateBatteryLevel(mv);
      device->updateBatteryAdv();
  }

  // Update the advertisement every time we get a new weight.
  // This is 10Hz by default on the HX711, but can be increased
  // to 80Hz via the RATE pin.
  if (currently_measuring == 1) {
    prev_weight = weight;
    int got_weight = getWeight();
    if (got_weight == 1) {
      num_samples += 1;
      measure_time = micros();
      device->updateWeight(weight);
      device->updateTimestamp(measure_time - start_measure_time);
      bool success = device->updateAdvData();
      if (success == 1) {
        num_packets += 1;
      }
    }
  }

  if (sleepTimeoutStart > 0 && ((millis() - sleepTimeoutStart) > light_sleep_timeout)) {
    // Will sleep until tare button pressed.
    // Will enter deep sleep if in light sleep for deep_sleep_timeout milliseconds.
    lightSleep();
    sleepTimeoutStart = millis();
  }

  // In case of overflow.
  if (curr_time < prev_time) {
    curr_time = prev_time = micros();
  }
  if (measure_time < start_measure_time) {
    curr_time = prev_time = micros();
  }

  // Measure sampling rate.
  if ((measure_time - hz_time) >= 1000000) {
    device_hz = num_samples;
    ble_hz = num_packets;
    num_samples = 0;
    num_packets = 0;
    hz_time = measure_time;
  }

  // Poll the battery
  // If battery level is low, change LED to red.
  float batt_level = getBatteryPercentage();
  if (batt_level <= 0.1) {
    setLEDColor(255, 0, 0);
  }
}

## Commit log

2025-07-12 Add calibration
2025-07-12 Advertisement rate set to ADC rate
2025-07-13 Add filtering
2025-07-14 add hardware
    [mito.kicad_pcb, mito.kicad_sch]
2025-08-26 Update prototype
2025-08-26 Upload hardware
    [PinHeader_1x07_P2.54mm_Vertical.step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]
2025-08-31 Fix issues with hardware.
    [mito.kicad_pcb, mito.kicad_sch]
2025-08-31 Add enclosure
    [enclosure.FCStd, load_cell.stl, mito.kicad_pcb]
2025-09-01 Breakout xiao pins
    [mito.kicad_pcb, mito.kicad_sch]
2025-09-03 mito V2 pcb
    [Molex_PicoBlade_53047-0210.stp, Molex_PicoBlade_53048-0210.stp, Panasonic_EVQPUJ_EVQPUA.step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]
2025-10-02 Update README with PCB image
2025-10-02 Save device code to EEPROM
2025-10-02 Add PCB image
2025-10-13 Update enclosure
    [button.step, enclosure2-Bottom.step, enclosure2-Bottom_window.step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]
2025-10-21 Working prototype
    [button.step, enclosure2-Bottom.step, enclosure2-Top.step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]
2025-10-27 Calibration over bleuart. Update enclosure.
    [button2.step, enclosure2.FCStd, enclosure3-Bottom.step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]
2025-10-27 bluetooth calibration working properly.
2025-11-11 Fix casting issue when raw reading is negative.
    [prototype.ino]
2025-12-02 Enter DFU via TARE button. No deep sleep in Tindeq mode.
2025-12-02 Small enclosure improvements
    [build_plate.3mf, build_plate.FCStd, build_plate.stl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]
2025-12-09 Update enclosure. Add PCB schematic.
    [enclosure_v3.3mf]
2026-01-06 Update enclosure print settings for PLA+ 2.0
    [enclosure_v3.3mf]
2026-01-06 Scale now notifies at >60Hz in Tindeq mode
2026-01-06 Better alpha values for weight and battery voltage smoothing
2026-01-06 Be clear about led colors when charging
2026-01-19 Small enclosure update
2026-02-27 Change how device name is set

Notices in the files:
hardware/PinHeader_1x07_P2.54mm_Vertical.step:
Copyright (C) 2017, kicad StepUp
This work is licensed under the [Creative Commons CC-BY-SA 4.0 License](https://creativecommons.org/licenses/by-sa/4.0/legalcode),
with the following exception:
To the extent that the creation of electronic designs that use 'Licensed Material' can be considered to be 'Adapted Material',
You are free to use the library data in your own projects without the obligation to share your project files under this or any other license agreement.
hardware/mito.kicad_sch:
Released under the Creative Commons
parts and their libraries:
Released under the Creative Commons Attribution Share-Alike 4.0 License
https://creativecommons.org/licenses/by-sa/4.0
